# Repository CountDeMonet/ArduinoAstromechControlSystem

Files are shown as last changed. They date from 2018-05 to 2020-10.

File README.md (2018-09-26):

# Arduino Astromech Control System
This has grown and is now full blown electronic package for dome rotation, sound, and motion based off Padawan360 (https://github.com/dankraus/padawan360)

Wiring Overview:
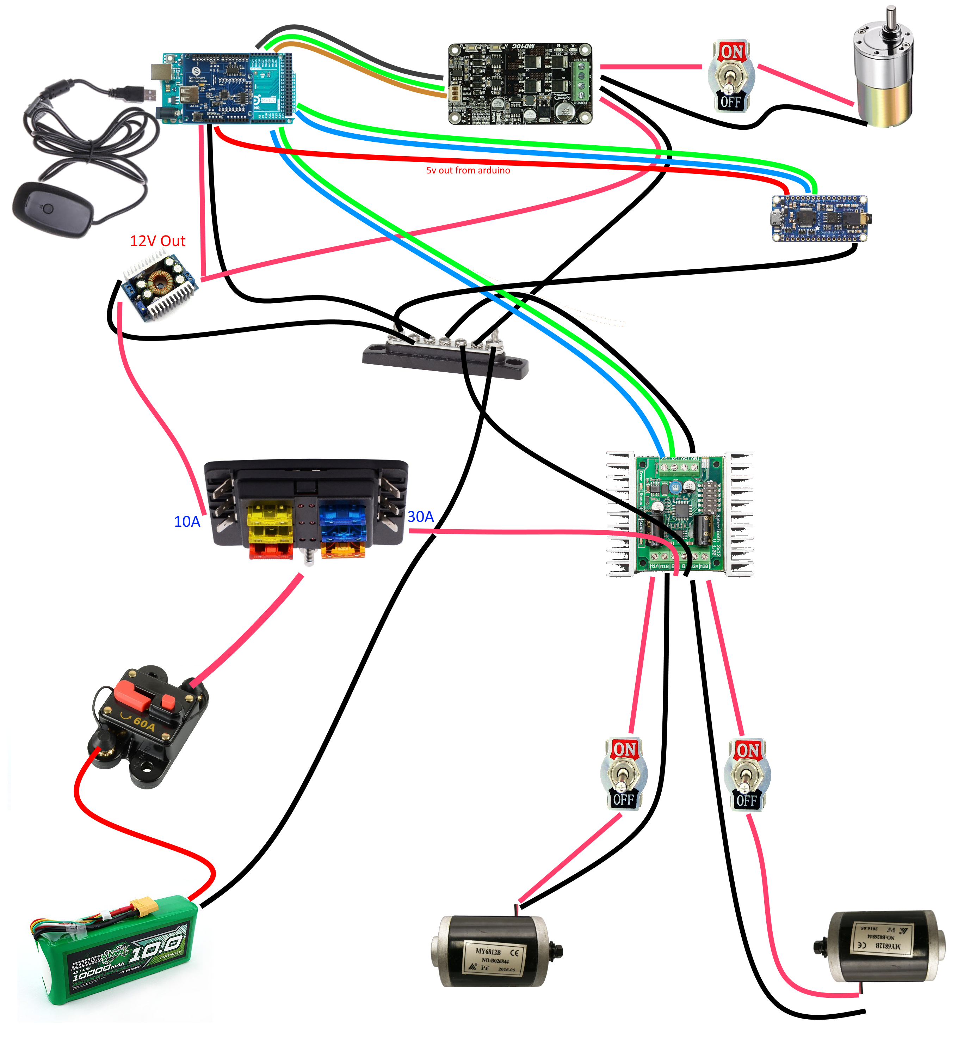
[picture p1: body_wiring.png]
wiring


I'm using the following components for Chopper:
 
Dome Lights:
* Arduino Nano: https://www.amazon.com/gp/product/B0713XK923
* 3 Individual Neopixels: https://www.amazon.com/kuman-WS2812B-Addressable-Arduino-littlergb/dp/B01M5BEO1C
* Two neopixel sticks: https://www.amazon.com/ACROBOTIC-8-Pixel-Addressable-24-Bit-WS2812B/dp/B07BF7TG6Z

Brain:
* Arduino Mega: https://www.amazon.com/gp/product/B01H4ZLZLQ
* USB Shield: https://www.amazon.com/gp/product/B0777DR3T6
* Xbox USB Receiver: https://www.amazon.com/gp/product/B00FAS1WDG

Audio:
* Adafruit Audio FX Board: https://www.amazon.com/gp/product/B00Q3U42DM
* Pyle 3.5” Inch Two Way: https://www.amazon.com/gp/product/B0007L8BT4
* Lepy 808 Amplifier: https://www.amazon.com/gp/product/B00OGZW54E

Dome Rotation:
* Lazy Susan: https://www.amazon.com/gp/product/B071FL5QR3
* Cytron Motor Controller: https://www.amazon.com/gp/product/B01M6ATGO4
* Uxcell dome motor: https://www.amazon.com/gp/product/B01KTZXVMO

Foot Drive:
* Sabertooth 32A: https://www.amazon.com/gp/product/B00O1722NG

Two locally sourced Razor E100 scooters

Main Power: https://hobbyking.com/en_us/multistar-high-capacity-4s-10000mah-multi-rotor-lipo-pack.html

I bought two of those lipos if I need to combine them for more time. or voltage

Misc Components:
* 20A Switches: https://www.amazon.com/gp/product/B012MYRB4E
* Fuse Box: https://www.amazon.com/gp/product/B074XS89H5
* Voltage Monitors: https://www.amazon.com/gp/product/B00YALUXH0
* 12A buck converter: https://www.amazon.com/gp/product/B071CWMRYD
* 60A Circuit Breaker: https://www.amazon.com/gp/product/B06Y5279ZH
* Wago 221: https://www.amazon.com/gp/product/B01N0LRTXZ

IMAGE ALT TEXT (https://www.youtube.com/watch?v=Q4jPT27Jjtw "Arduino Dome Rotation Controller")

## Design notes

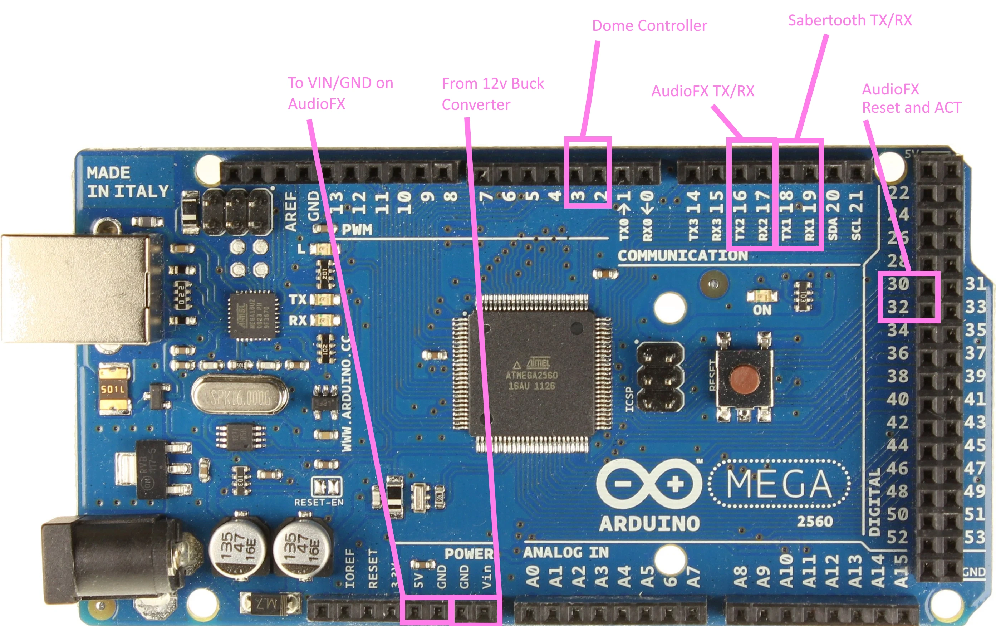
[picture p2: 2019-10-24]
Arduino-Mega-2560-Pinout.webp

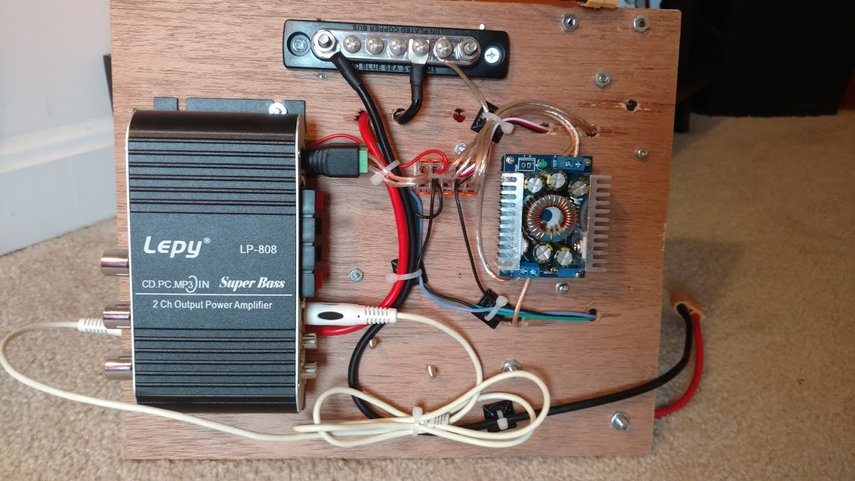
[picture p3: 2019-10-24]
chopper_board_back.jpg

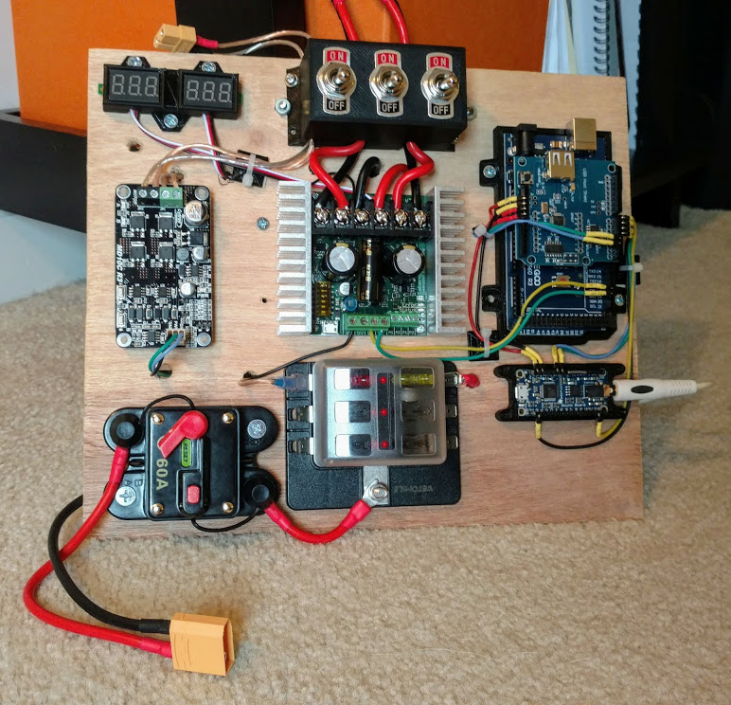
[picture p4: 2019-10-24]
chopper_board_front.jpg

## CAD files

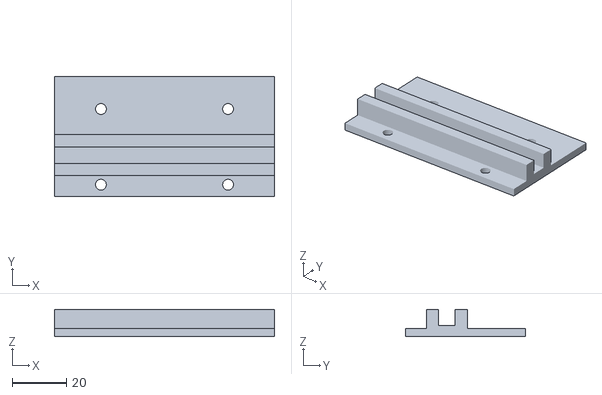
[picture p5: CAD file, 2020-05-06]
Models/body_electronics_mount_center.stl
81.0 x 44.3 x 10.00

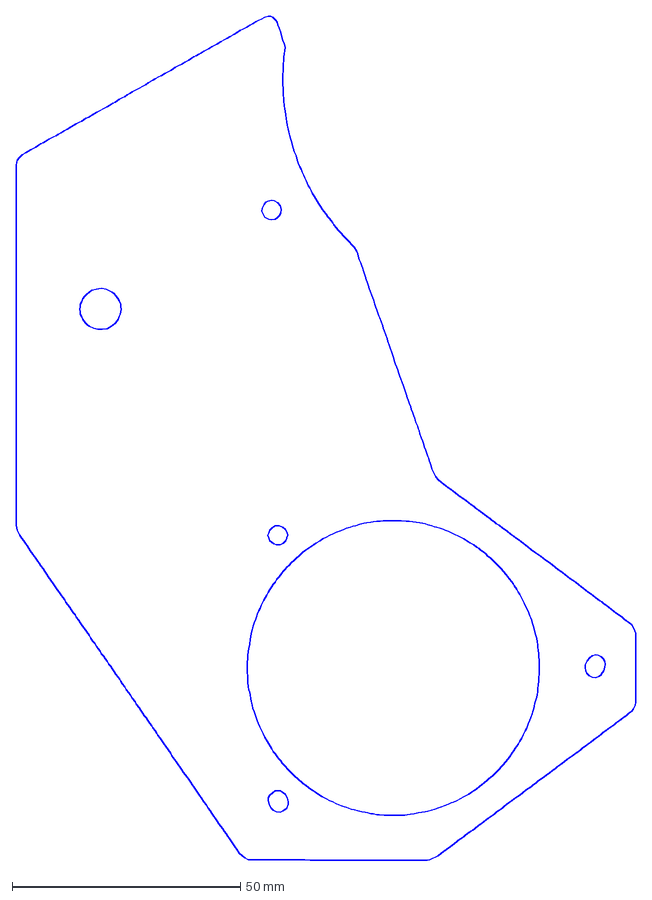
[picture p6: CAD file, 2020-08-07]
Models/FlatPackE100FootDrive/Scooter_drive_center_x2_v2.dxf
135.6 x 184.8 mm

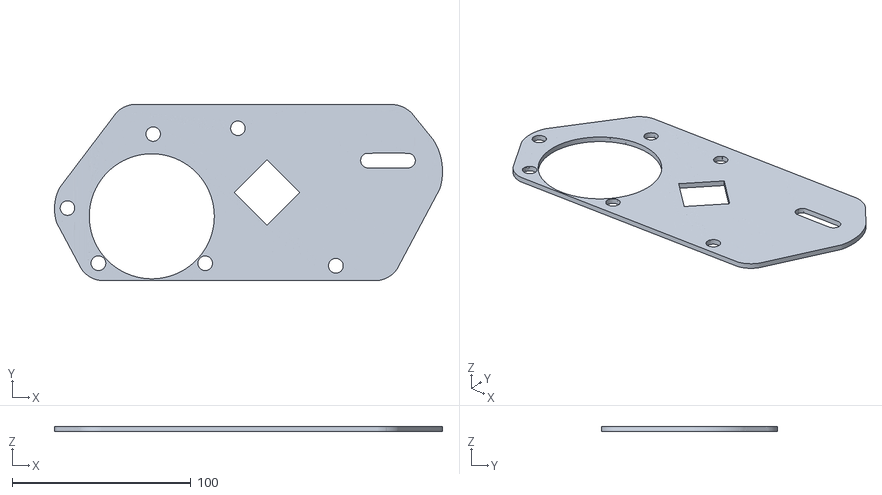
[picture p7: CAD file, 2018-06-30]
Models/FlatPackE100FootDrive/Scooter_drive_side_inner.stl
217.3 x 98.5 x 3.01

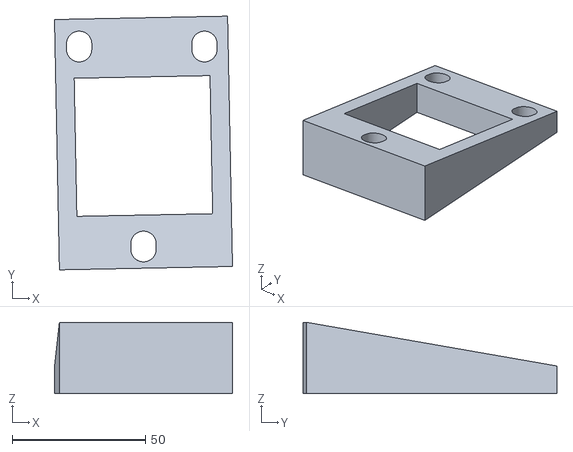
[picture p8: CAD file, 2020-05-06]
Models/new_wheel_mount.stl
66.8 x 95.3 x 26.8

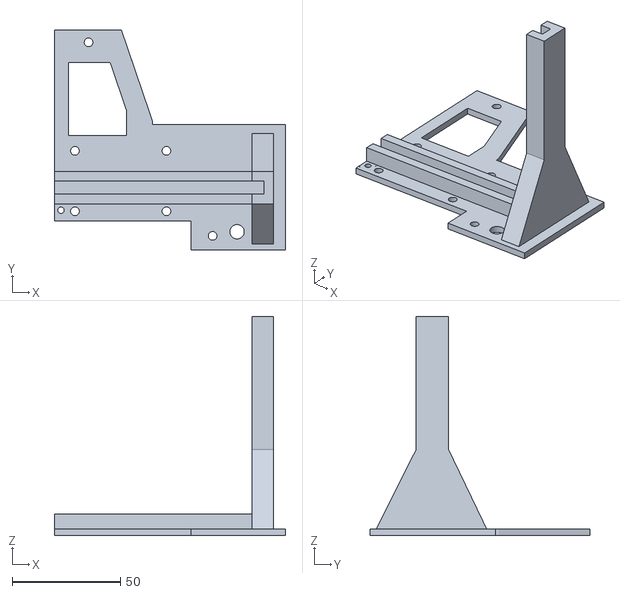
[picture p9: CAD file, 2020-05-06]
Models/body_electronics_mount_right.stl
106.5 x 101.6 x 101.0

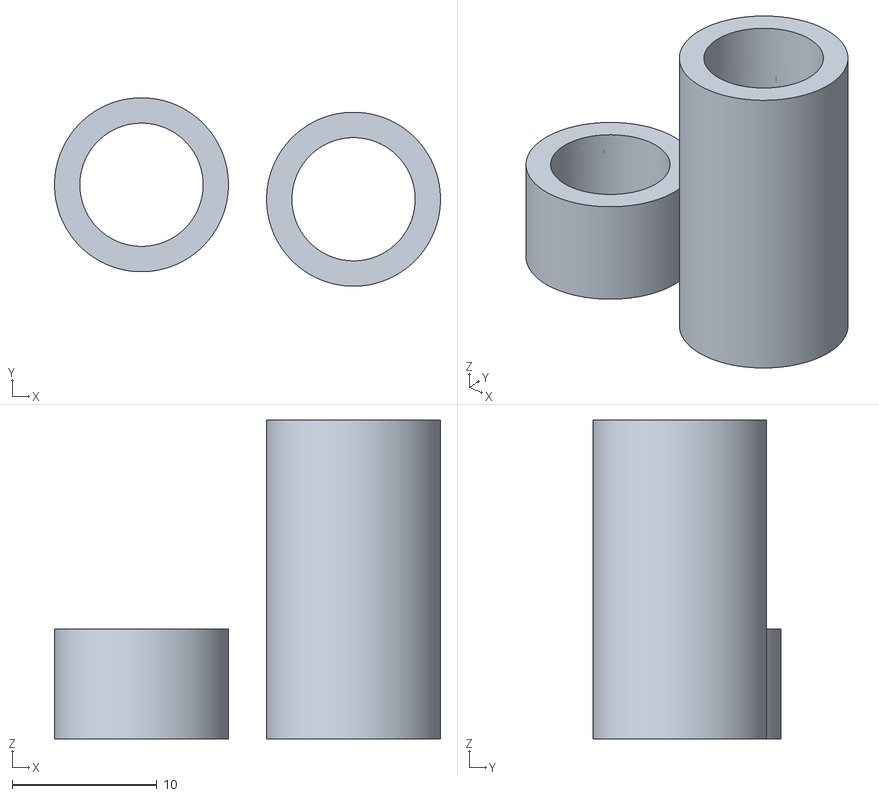
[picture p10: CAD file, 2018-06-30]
Models/FlatPackE100FootDrive/Scooter_drive_spacers_rear_wheel.stl
26.6 x 13.0 x 22.0

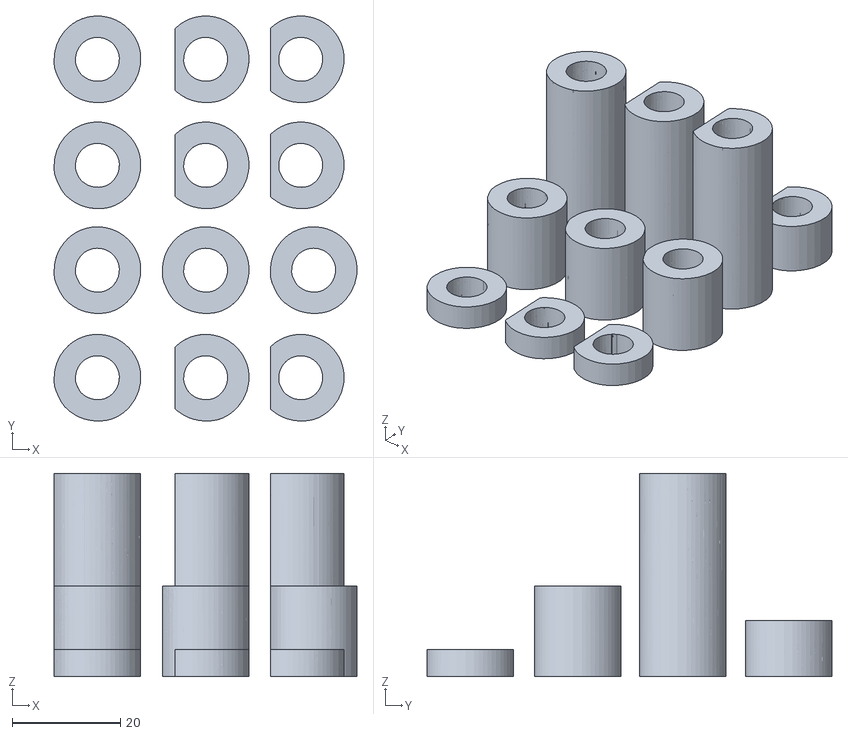
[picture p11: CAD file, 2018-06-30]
Models/FlatPackE100FootDrive/Scooter_drive_spacers_motor_mount.stl
56.0 x 74.8 x 37.5

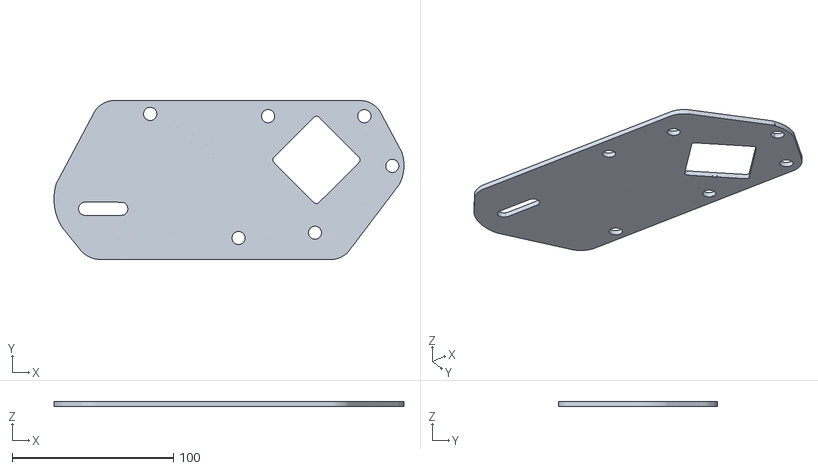
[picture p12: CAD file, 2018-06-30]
Models/FlatPackE100FootDrive/Scooter_drive_side_outer.stl
217.3 x 98.5 x 3.00

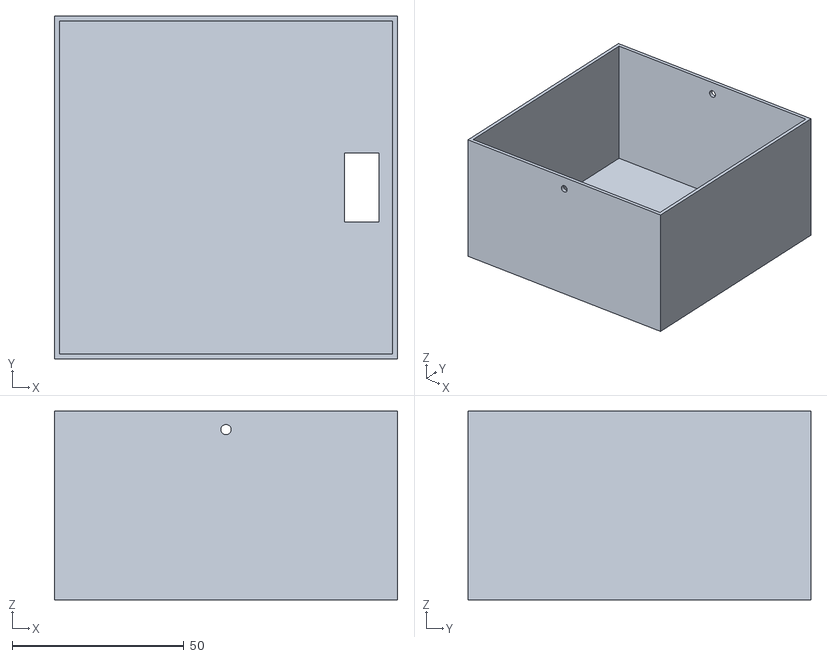
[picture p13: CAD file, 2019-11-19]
Models/speaker_body.stl
100.0 x 100.0 x 55.0

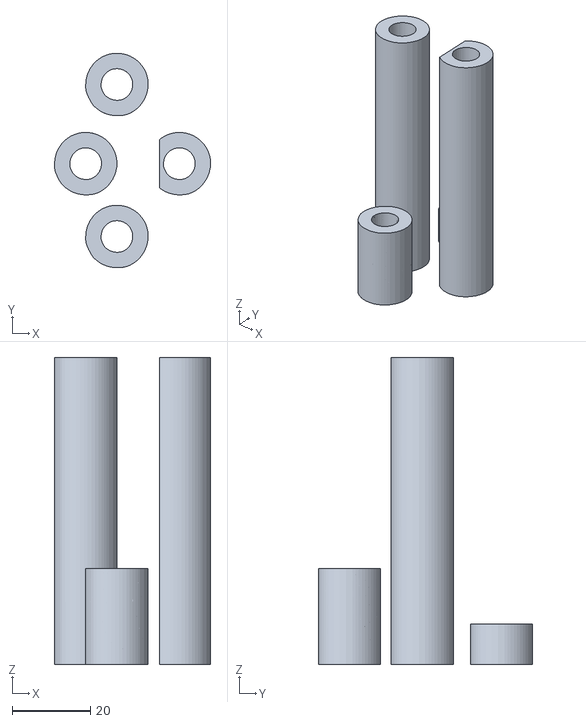
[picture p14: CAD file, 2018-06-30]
Models/FlatPackE100FootDrive/Scooter_drive_spacers_frame.stl
40.0 x 55.0 x 78.7

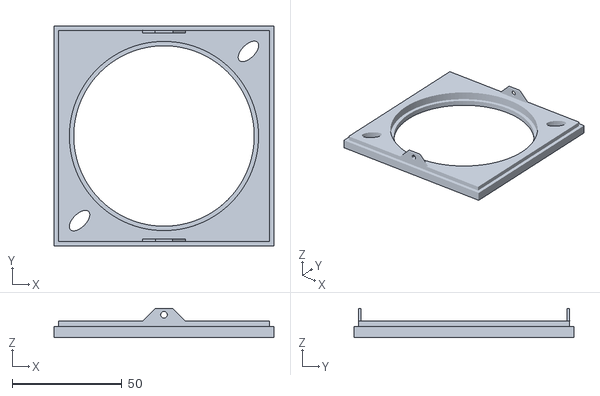
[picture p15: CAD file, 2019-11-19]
Models/speaker_mount.stl
100.0 x 100.0 x 13.4

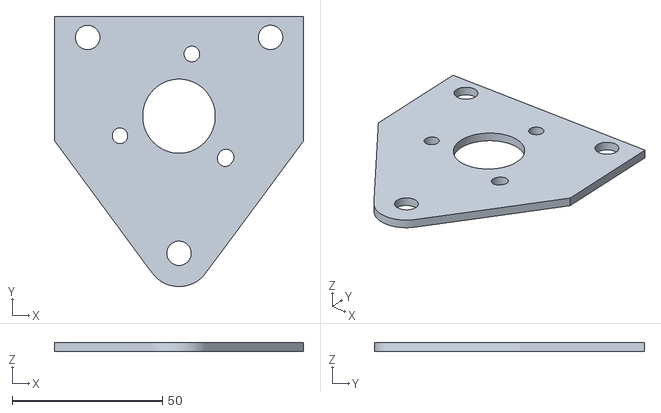
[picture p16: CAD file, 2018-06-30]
Models/FlatPackE100FootDrive/Scooter_drive_motor_mount.stl
82.9 x 89.8 x 3.00

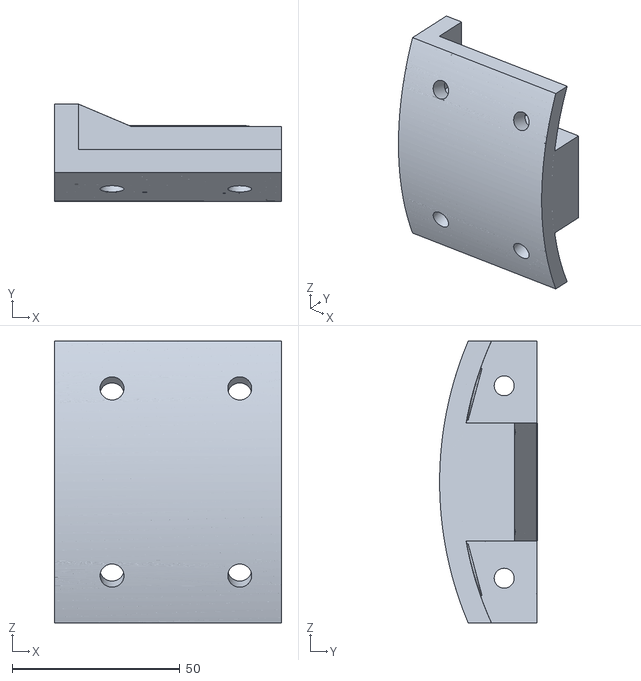
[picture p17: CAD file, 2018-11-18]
Models/strong_wood_mount_front.stl
67.8 x 29.2 x 84.1

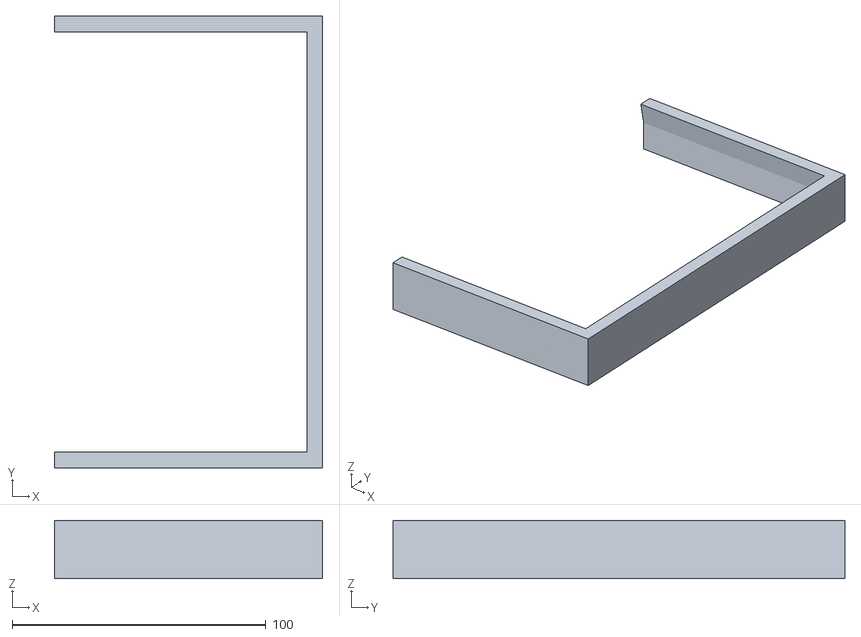
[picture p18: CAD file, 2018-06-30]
Models/LockingStrip1_2.stl
105.8 x 178.2 x 23.0

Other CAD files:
Models/body_electronics_mount_left.stl
Models/LockingStrip1_0.stl
Models/LockingStrip1_3.stl
Models/LockingStrip1_1.stl
Models/AmazonMotorBracket.stl
Models/FlatPackE100FootDrive/Scooter_drive_motor_mount.dxf
Models/FlatPackE100FootDrive/Scooter_drive_side_inner.dxf
Models/FlatPackE100FootDrive/Scooter_drive_side_outer.dxf
Models/RingGear_77_0.stl
Models/RingGear_77_1.stl
Models/RingGear_77_2.stl
Models/RingGear_77_3.stl
Models/RingGear_77_4.stl
Models/RingGear_77_5.stl
Models/RingGear_77_6.stl
Models/RingGear_77_7.stl
Models/RingGear_77_8.stl
Models/battery_mount.stl
Models/buck_converter_mount.stl
Models/dome_adapter_with_platform.stl
Models/dome_electronics_holder.stl
Models/eye_neo_holder .stl
Models/leg_lock_v3.stl
Models/motor gear_77.stl
Models/power_bar_holder.stl
Models/strong_wheel_mount.stl
Models/strong_wood_mount_back.stl
Models/switch_housing.stl
Models/voltage_holder.stl

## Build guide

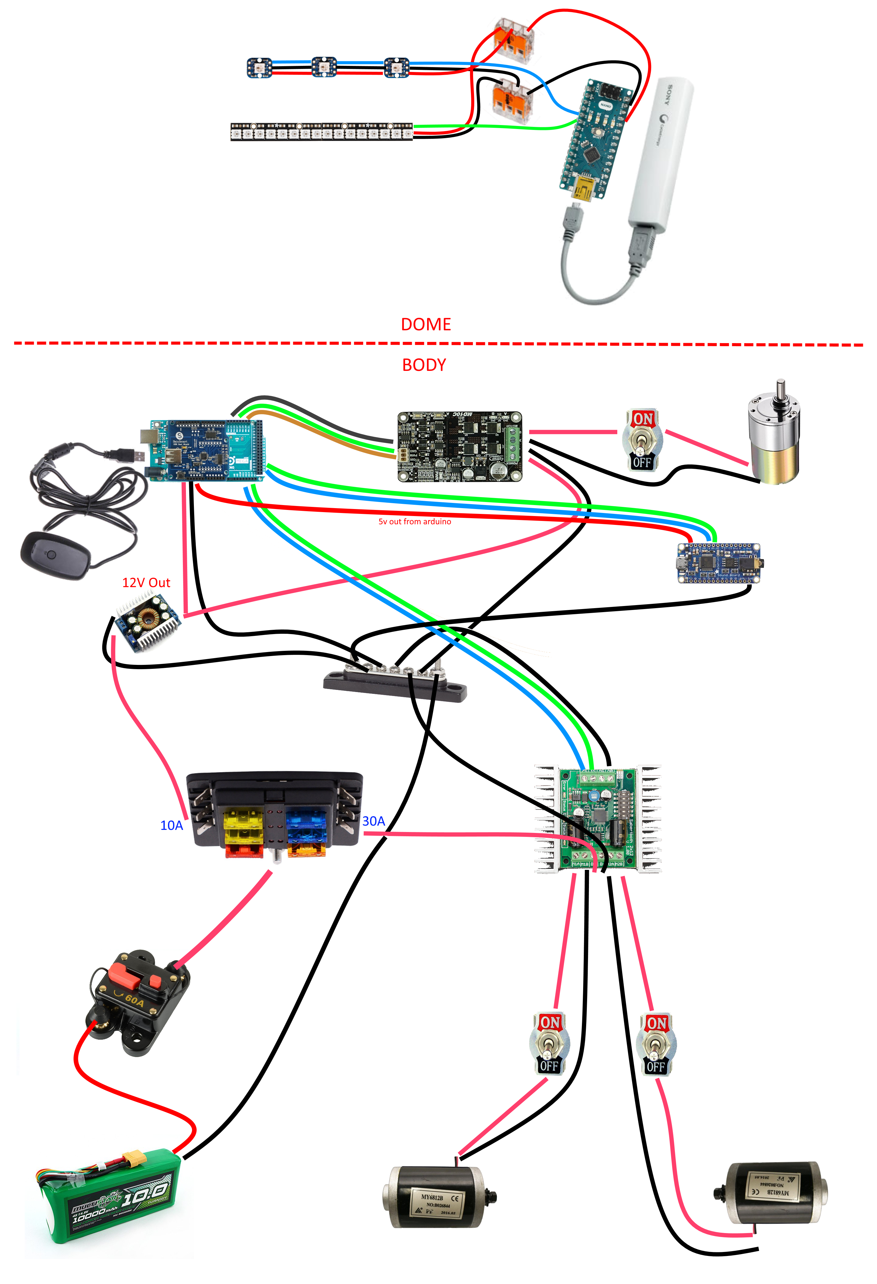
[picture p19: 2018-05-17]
chopper_wiring.png

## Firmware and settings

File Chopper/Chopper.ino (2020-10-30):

// =======================================================================================
// /////////////////////////Padawan360 Body Code - Mega v1.0 ////////////////////////////////////
// =======================================================================================
/*
  by Dan Kraus
  dskraus@gmail.com
  Astromech: danomite4047

  Heavily influenced by DanF's Padwan code which was built for Arduino+Wireless PS2
  controller leveraging Bill Porter's PS2X Library. I was running into frequent disconnect
  issues with 4 different controllers working in various capacities or not at all. I decided
  that PS2 Controllers were going to be more difficult to come by every day, so I explored
  some existing libraries out there to leverage and came across the USB Host Shield and it's
  support for PS3 and Xbox 360 controllers. Bluetooth dongles were inconsistent as well
  so I wanted to be able to have something with parts that other builder's could easily track
  down and buy parts even at your local big box store.

*** Modified
  by Eric Banker
  ebanker@vineripeconsulting.com
  Astromech: C0UNTDEM0NET

  This has been modified to use some cheaper components like an Adafruit Audio FX board and a
  Cytron motor controller for the dome rotation. Some features have been removed as this code
  is being used in a Chopper build.

  https://astromech.net/forums/showthread.php?34866-C0unt-s-Chopper-Build

  Hardware:
  Arduino Mega
  USB Host Shield
  Microsoft Xbox 360 Controller
  Xbox 360 USB Wireless Reciver
  Sabertooth 2x Motor Controller
  Cytron 10A Motor Controller
  Adafruit AudioFX Board

  Set Sabertooth 2x32/2x25/2x12 Dip Switches 1 and 2 Down, All Others Up
*/

#include <Sabertooth.h>
#include <XBOXRECV.h>
#include <SoftwareSerial.h>
#include "Adafruit_Soundboard.h"

//************************** Set speed and turn speeds here************************************//

//set these 3 to whatever speeds work for you. 0-stop, 127-full speed.
const byte DRIVESPEED1 = 80;
//Recommend beginner: 50 to 75, experienced: 100 to 127, I like 100.
const byte DRIVESPEED2 = 100;
//Set to 0 if you only want 2 speeds.
const byte DRIVESPEED3 = 127;

byte drivespeed = DRIVESPEED1;

// the higher this number the faster the droid will spin in place, lower - easier to control.
// Recommend beginner: 40 to 50, experienced: 50 $ up, I like 70
const byte TURNSPEED = 60;
// If using a speed controller for the dome, sets the top speed. You'll want to vary it potenitally
// depending on your motor.
const byte DOMESPEED = 230;

// Set the baude rate for the Sabertooth motor controller (feet)
// 9600 is the default baud rate for Sabertooth packet serial.
// for packetized options are: 2400, 9600, 19200 and 38400. I think you need to pick one that works
// and I think it varies across different firmware versions.
const int SABERTOOTHBAUDRATE = 9600;

// Compensation is for deadband/deadzone checking. There's a little play in the neutral zone
// which gets a reading of a value of something other than 0 when you're not moving the stick.
// It may vary a bit across controllers and how broken in they are, sometimes 360 controllers
// develop a little bit of play in the stick at the center position. You can do this with the
// direct method calls against the Syren/Sabertooth library itself but it's not supported in all
// serial modes so just manage and check it in software here
// use the lowest number with no drift
// DOMEDEADZONERANGE for the left stick, DRIVEDEADZONERANGE for the right stick
const byte DOMEDEADZONERANGE = 45;
const byte DRIVEDEADZONERANGE = 20;

/* define the pins in use */
Sabertooth Sabertooth2x(128, Serial1);

// dome controller
#define domeDirPin 2
#define domeSpeedPin 3

// soundboard pins and setup
#define SFX_RST 30
const int ACT = 32;    // this allows us to know if the audio is playing

// init the audio board
Adafruit_Soundboard sfx = Adafruit_Soundboard( &Serial2, NULL, SFX_RST);

// Set some defaults for start up
// 0 = drive motors off ( right stick disabled ) at start
boolean isDriveEnabled = false;

// Automated function variables
// Used as a boolean to turn on/off automated dome turns
boolean automateDome = false;
unsigned long domeAutomateMillis = 0;
byte domeAutomateDelay = random(5, 15); // set this to min and max seconds between sounds
unsigned long domeAutoMoveMillis = 0;
unsigned long domeAutoMoveDelay = 400; // how long the dome will move for
bool isDomeMoving = false;  // is the dome rotating due to automation
byte turnDirection = 1;  // which direction to turn

// Used as a boolean to turn on/off automated audio chirps
boolean automateAudio = false;
unsigned long audioAutomateMillis = 0;
byte audioAutomateDelay = random(5, 10); // set this to min and max seconds between sounds

// throttle and stick variables
char driveThrottle = 0;
char sticknum = 0;
char domeThrottle = 0;
char turnThrottle = 0;

// first bootup check params
boolean hasPlayedAlert = false;
boolean firstLoadOnConnect = false;

USB Usb;
XBOXRECV Xbox(&Usb);

void setup() {
  // softwareserial at 9600 baud for the audio board
  Serial2.begin(9600);

  // see if we have the soundboard
  // If we fail to communicate, loop forever for now but it would be nice to warn the user somehow
  if (!sfx.reset()) {
    while (1);
  }

  // set act modes for the fx board
  pinMode(ACT, INPUT);

  // foot controller
  Serial1.begin(SABERTOOTHBAUDRATE);
  Sabertooth2x.autobaud();
  Sabertooth2x.drive(0);
  Sabertooth2x.turn(0);
  Sabertooth2x.setTimeout(950);

  // dome controller
  pinMode(domeDirPin, OUTPUT);
  pinMode(domeSpeedPin, OUTPUT);

  while (!Serial);
  if (Usb.Init() == -1) {
    while (1); //halt
  }
}

void loop() {
  Usb.Task();

  bool needToPlayAudio = false;
  int randomAudioTrack = -1;
  char nextAudioTrack[12] = "SHORTCKTOGG";

  // find out of the audio board is playing audio
  int playing = digitalRead(ACT);

  // if we're not connected, return so we don't bother doing anything else.
  // set all movement to 0 so if we lose connection we don't have a runaway droid!
  // a restraining bolt and jawa droid caller won't save us here!
  if (!Xbox.XboxReceiverConnected || !Xbox.Xbox360Connected[0]) {
    Sabertooth2x.drive(0);
    Sabertooth2x.turn(0);
    analogWrite(domeSpeedPin, 0);

    // if we have been connected before let us know we're powering down
    if( firstLoadOnConnect == false && hasPlayedAlert == false ){
      // let everyone know we lost connection
      hasPlayedAlert = true;
      strncpy(nextAudioTrack, "MOTIV   OGG", 12);
      playAudioTrack(nextAudioTrack, playing);
    }
    
    firstLoadOnConnect = false;    
    return;
  }

  // After the controller connects, Blink all the LEDs so we know drives are disengaged at start
  if (!firstLoadOnConnect) {
    firstLoadOnConnect = true;
    hasPlayedAlert = false;
    strncpy(nextAudioTrack, "STARTSNDOGG", 12);
    needToPlayAudio = true;
    Xbox.setLedMode(ROTATING, 0);
  }

  if (Xbox.getButtonClick(XBOX, 0)) {
    if (Xbox.getButtonPress(L1, 0) && Xbox.getButtonPress(R1, 0)) {
      Xbox.disconnect(0);
      strncpy(nextAudioTrack, "MOTIV   OGG", 12);
      needToPlayAudio = true;
    }
  }

  // enable / disable right stick (droid movement) & play a sound to signal motor state
  if (Xbox.getButtonClick(START, 0)) {
    if (isDriveEnabled) {
      isDriveEnabled = false;
      Xbox.setLedMode(ROTATING, 0);
      strncpy(nextAudioTrack, "CHORTLE OGG", 12);
      needToPlayAudio = true;
    } else {
      isDriveEnabled = true;
      strncpy(nextAudioTrack, "PATROL  OGG", 12);
      needToPlayAudio = true;

      //When the drive is enabled, set our LED accordingly to indicate speed
      if (drivespeed == DRIVESPEED1) {
        Xbox.setLedOn(LED1, 0);
      } else if (drivespeed == DRIVESPEED2 && (DRIVESPEED3 != 0)) {
        Xbox.setLedOn(LED2, 0);
      } else {
        Xbox.setLedOn(LED3, 0);
      }
    }
  }

  // Automation 
  // Hold R1 and Press Up to turn on/off dome automation
  if (Xbox.getButtonClick(UP, 0)) {
    // volume up
    if (Xbox.getButtonPress(R1, 0)) {
      if (automateDome == true) {
        isDomeMoving = false;
        automateDome = false;
      } else {
        automateDome = true;
        strncpy(nextAudioTrack, "T30     OGG", 12);
        needToPlayAudio = true;
      }
    }
  }

  // Moves the dome around from time to time when automation is turned on  
  if (automateDome) {
    unsigned long currentMillis = millis();

    if ( isDomeMoving == false ) {
      if ((unsigned long)(currentMillis - domeAutomateMillis) > (unsigned long)(domeAutomateDelay * 1000)) {
        domeAutomateMillis = millis();
        
        // set the direction
        if ( turnDirection == 1 ) {
          digitalWrite(domeDirPin, LOW);
          analogWrite(domeSpeedPin, 150);
        } else {
          digitalWrite(domeDirPin, HIGH);
          analogWrite(domeSpeedPin, 160);
        }

        domeAutoMoveMillis = millis();
        isDomeMoving = true;
      }
    } else {
      if ((unsigned long)(currentMillis - domeAutoMoveMillis) > (unsigned long)(domeAutoMoveDelay)) {
        // stop the dome
        analogWrite(domeSpeedPin, 0);

        // change the direction for the next go
        if (turnDirection == 1) {
          turnDirection = -1;
        } else {
          turnDirection = 1;
        }

        // sets the mix, max seconds between automation actions
        domeAutomateDelay = random(5, 15);
        isDomeMoving = false;
      }
    }
  }

  // Hold R1 and Press Down to turn on/off audio automation
  if (Xbox.getButtonClick(DOWN, 0)) {
    //volume down
    if (Xbox.getButtonPress(R1, 0)) {
      if (automateAudio == true) {
        automateAudio = false;
      } else {
        automateAudio = true;
        strncpy(nextAudioTrack, "T14     OGG", 12);
        needToPlayAudio = true;
      }
    }
  }
  
  if ( automateAudio ) { 
    unsigned long currentMillis = millis();
    if ((unsigned long)(currentMillis - audioAutomateMillis) > (unsigned long)(audioAutomateDelay * 1000)) {
      audioAutomateMillis = millis();
      needToPlayAudio = true;
      randomAudioTrack = 4;
      audioAutomateDelay = random(5, 15);
    }
  }
 
  // GENERAL SOUND PLAYBACK AND DISPLAY CHANGING
  // A Button and A combo Buttons
  if (Xbox.getButtonClick(A, 0)) {
    if (Xbox.getButtonPress(L2, 0) && Xbox.getButtonPress(R2, 0)) {
      strncpy(nextAudioTrack, "CANTINA OGG", 12);    
      automateAudio = false;           
      needToPlayAudio = true;
    } else if (Xbox.getButtonPress(L1, 0) && Xbox.getButtonPress(R2, 0)) {
      strncpy(nextAudioTrack, "MAHNA   OGG", 12);   
      automateAudio = false;            
      needToPlayAudio = true;
    } else if (Xbox.getButtonPress(L1, 0)) {
      strncpy(nextAudioTrack, "T02     OGG", 12);
      automateAudio = false;
      needToPlayAudio = true;
    } else if (Xbox.getButtonPress(L2, 0)) {
      strncpy(nextAudioTrack, "T06     OGG", 12);
      automateAudio = false;
      needToPlayAudio = true;
    } else if (Xbox.getButtonPress(R1, 0)) {
      strncpy(nextAudioTrack, "T10     OGG", 12);
      automateAudio = false;
      needToPlayAudio = true;
    } else {
      automateAudio = false;
      needToPlayAudio = true;
      randomAudioTrack = 2;
    }
  }

  // B Button and B combo Buttons
  if (Xbox.getButtonClick(B, 0)) {
    if (Xbox.getButtonPress(L2, 0) && Xbox.getButtonPress(R2, 0)) {
      strncpy(nextAudioTrack, "REBEL   OGG", 12);               
      automateAudio = false;       
      needToPlayAudio = true;
    }else if (Xbox.getButtonPress(L1, 0) && Xbox.getButtonPress(R2, 0)) {
      strncpy(nextAudioTrack, "ALIVE   OGG", 12);               
      automateAudio = false;       
      needToPlayAudio = true;
    }else if (Xbox.getButtonPress(L1, 0)) {
      strncpy(nextAudioTrack, "T03     OGG", 12);
      automateAudio = false;       
      needToPlayAudio = true; 
    } else if (Xbox.getButtonPress(L2, 0)) {
      strncpy(nextAudioTrack, "T07     OGG", 12);
      automateAudio = false;       
      needToPlayAudio = true;
    } else if (Xbox.getButtonPress(R1, 0)) {
      strncpy(nextAudioTrack, "T11     OGG", 12);
      automateAudio = false;       
      needToPlayAudio = true;
    } else {
      automateAudio = false;       
      needToPlayAudio = true;
      randomAudioTrack = 3;
    }
  }

  // X Button and X combo Buttons
  if (Xbox.getButtonClick(X, 0)) {
    if (Xbox.getButtonPress(L2, 0) && Xbox.getButtonPress(R2, 0)) {
      strncpy(nextAudioTrack, "MARCH   OGG", 12);
      automateAudio = false;       
      needToPlayAudio = true;
    }else if (Xbox.getButtonPress(L1, 0) && Xbox.getButtonPress(R2, 0)) {
      strncpy(nextAudioTrack, "STYLE   OGG", 12);
      automateAudio = false;       
      needToPlayAudio = true;
    }else if (Xbox.getButtonPress(L1, 0)) {
      strncpy(nextAudioTrack, "T04     OGG", 12);
      automateAudio = false;       
      needToPlayAudio = true;
    } else if (Xbox.getButtonPress(L2, 0)) {
      strncpy(nextAudioTrack, "T08     OGG", 12);
      automateAudio = false;       
      needToPlayAudio = true;
    } else if (Xbox.getButtonPress(R1, 0)) {
      strncpy(nextAudioTrack, "T12     OGG", 12);
      automateAudio = false;       
      needToPlayAudio = true;
    } else {
      automateAudio = false;       
      needToPlayAudio = true;
      randomAudioTrack = 4;
    }
  }

  // Y Button and Y combo buttons
  if (Xbox.getButtonClick(Y, 0)) {
    if (Xbox.getButtonPress(L2, 0) && Xbox.getButtonPress(R2, 0)) {
      strncpy(nextAudioTrack, "R2BDAY1 OGG", 12);                  
      automateAudio = false;       
      needToPlayAudio = true;
    } else if (Xbox.getButtonPress(L1, 0)) {
      strncpy(nextAudioTrack, "T01     OGG", 12);
      automateAudio = false;       
      needToPlayAudio = true;
    } else if (Xbox.getButtonPress(L2, 0)) {
      strncpy(nextAudioTrack, "T05     OGG", 12);
      automateAudio = false;       
      needToPlayAudio = true;
    } else if (Xbox.getButtonPress(R1, 0)) {
      strncpy(nextAudioTrack, "T09     OGG", 12);
      automateAudio = false;       
      needToPlayAudio = true;
    } else {
      automateAudio = false;       
      needToPlayAudio = true;
      randomAudioTrack = 1;
    }
  }

  // Change drivespeed if drive is eabled
  // Press Right Analog Stick (R3)
  // Set LEDs for speed - 1 LED, Low. 2 LED - Med. 3 LED High
  if (Xbox.getButtonClick(R3, 0) && isDriveEnabled) {
    //if in lowest speed
    if (drivespeed == DRIVESPEED1) {
      //change to medium speed and play sound 3-tone
      drivespeed = DRIVESPEED2;
      Xbox.setLedOn(LED2, 0);
    } else if (drivespeed == DRIVESPEED2 && (DRIVESPEED3 != 0)) {
      //change to high speed and play sound scream
      drivespeed = DRIVESPEED3;
      Xbox.setLedOn(LED3, 0);
    } else {
      //we must be in high speed
      //change to low speed and play sound 2-tone
      drivespeed = DRIVESPEED1;
      Xbox.setLedOn(LED1, 0);
    }
  }

  // FOOT DRIVES
  // Xbox 360 analog stick values are signed 16 bit integer value
  // Sabertooth runs at 8 bit signed. -127 to 127 for speed (full speed reverse and  full speed forward)
  // Map the 360 stick values to our min/max current drive speed
  sticknum = (map(Xbox.getAnalogHat(RightHatY, 0), -32768, 32767, -drivespeed, drivespeed));
  if (sticknum > -DRIVEDEADZONERANGE && sticknum < DRIVEDEADZONERANGE) {
    // stick is in dead zone - don't drive
    driveThrottle = 0;
  } else {
    if (driveThrottle < sticknum) {
      driveThrottle = sticknum;
    } else if (driveThrottle > sticknum) {
      driveThrottle = sticknum;
    }
  }
  turnThrottle = map(Xbox.getAnalogHat(RightHatX, 0), -32768, 32767, -TURNSPEED, TURNSPEED);

  // DRIVE!
  // right stick (drive)
  if (isDriveEnabled) {
    // Only do deadzone check for turning here.
    if (turnThrottle > -DRIVEDEADZONERANGE && turnThrottle < DRIVEDEADZONERANGE) {
      // stick is in dead zone - don't turn
      turnThrottle = 0;
    }
    Sabertooth2x.turn(-turnThrottle);
    Sabertooth2x.drive(driveThrottle);
  }

  // DOME DRIVE! ignore if dome automation is moving the dome
  if ( isDomeMoving == false ) {
    int domeThrottle = 0;
    byte directon = 0;
    int pwmVal = 0;

    domeThrottle = (map(Xbox.getAnalogHat(LeftHatX, 0), -32768, 32767, -500, 500));
    if (domeThrottle > -DOMEDEADZONERANGE && domeThrottle < DOMEDEADZONERANGE) {
      //stick in dead zone - don't spin dome
      domeThrottle = 0;
    }

    if ( domeThrottle > 0 ) {
      // forward
      directon = 0;
      pwmVal = map(domeThrottle, 0, 500, 0, DOMESPEED);
      digitalWrite(domeDirPin, HIGH);
    } else {
      // backward
      directon = 1;
      pwmVal = map(domeThrottle, 0, -500, 0, DOMESPEED);
      digitalWrite(domeDirPin, LOW);
    }

    // if near center stick ignore
    if ( pwmVal < DOMEDEADZONERANGE ) {
      pwmVal = 0;
    }
    // if somehow over speed set max speed
    if ( pwmVal > 255 ) {
      pwmVal = 255;
    }

    // sends the values to the motor controller
    analogWrite(domeSpeedPin, pwmVal);
  }

  if ( needToPlayAudio == true ) {
    if ( randomAudioTrack == -1 ) {
      playAudioTrack(nextAudioTrack, playing);
    } else {
      switch (randomAudioTrack) {
        case 1:
          playAudio(random(0, 14), playing);
          break;
        case 2:
          playAudio(random(15, 49), playing);
          break;
        case 3:
          playAudio(random(50, 57), playing);
          break;
        case 4:
          playAudio(random(58, 71), playing);
          break;
        case 5:
          playAudio(random(15, 28), playing);
          break;
      }
    }
  }

  delay(1);
}

/* ************* Audio Board Helper Functions ************* */
// helper function to play a track by name on the audio board
void playAudioTrack( char trackname[], int playing ) {
  // stop track if one is going
  if (playing == 0) {
    sfx.stop();
  }

  // now go play
  if (sfx.playTrack(trackname)) {
    sfx.unpause();
  }
}

// helper function to play a track by number on the audio board
void playAudio( uint8_t tracknum, int playing ) {
  // stop track if one is going
  if (playing == 0) {
    sfx.stop();
  }

  // now go play
  if (sfx.playTrack(tracknum)) {
    sfx.unpause();
  }
}

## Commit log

2018-03-14 Some of the models used.
    The ring gear is a scaled version of MRBADDELEY's R2 gear. The Motor gear is scaled as well but keeps the correct motor mount size.
    The amazon motor bracket is modified specifically for the amazon motor.
    The dome adapter is a variation on the common dome adapter for the 14 inch lazy susan but it includes a platform for mounting an arduino and a 1000mAh 3 cell lipo for powering it.
    The leg lock is for locking chopper in 3 leg or standing mode.
    [AmazonMotorBracket.stl, DomeAdapter_with_platform.stl, RingGear_77_0.stl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]
2018-05-10 Adding the in process switch over to padawan 360 with the cyctron motor controller.
2018-05-14 added audiofx board handling
2018-05-17 add wiring diagram
2018-05-25 update models
    [battery_mount.stl, body_electronics_mount_left.stl, body_electronics_mount_right.stl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]
2018-05-25 switch to an uno and disable sounds for time being. Debugging the drive system
2018-05-29 switch back to mega, use serial 1 for saber and 2 for fx board. Rework dome automation so no delays
    [Chopper.ino]
2018-06-03 get rid of the ramping. It makes driving so much harder since it's only applied to forward and reverse.
    [Chopper.ino]
2018-06-30 adding in the flatpack drive system
    [Scooter_drive_motor_mount.stl, Scooter_drive_side_inner.stl, Scooter_drive_side_outer.stl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]
2018-06-30 Locking strip parts for the bottom of the foot shell
    [LockingStrip1_0.stl, LockingStrip1_1.stl, LockingStrip1_2.stl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]
2018-07-20 fix dome automation direction switch
    [Chopper.ino]
2018-07-27 Add DXF Files for the main parts if you want to lazer cut or cnc the drive parts
    [Scooter_drive_center_x2_v2.dxf, Scooter_drive_motor_mount.dxf, Scooter_drive_side_inner.dxf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]
2018-11-01 updated model to allow printing easily for strength
    [strong_wood_mount_front.stl]
2018-11-18 Rotate model and netfabb optimized
    [strong_wood_mount_front.stl]
2019-10-24 some images and wiring help
2019-11-19 totally forgot the speaker mounts
    [speaker_body.stl, speaker_mount.stl]
2020-05-06 Stronger body mounts that have screw holes for fixing to a plywood base.
    Also adds different mount for the center wheel mount. I'm upgrading to a new caster and needed a different mount
    [body_electronics_mount_center.stl, body_electronics_mount_left.stl, body_electronics_mount_right.stl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]
2020-08-07 Adjustements to the dxf files so they can be cut by sendcutsend.com. ~$50 a foot
    [Scooter_drive_center_x2_v2.dxf, Scooter_drive_motor_mount.dxf, Scooter_drive_side_inner.dxf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]
2020-10-30 decouple audio and dome rotation automation.
    also remove volume and reuse for automation since volume is not working on the adafruit board
    [Chopper.ino]
2020-10-30 fix dome automation and reduce dome motor run time
    [Chopper.ino]
